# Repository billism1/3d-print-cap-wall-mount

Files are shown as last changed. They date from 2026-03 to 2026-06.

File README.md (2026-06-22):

# Cap Wall Mount – Hat Display System

> *Yes, it's a wall hook for hats. No, I didn't need to overthink it this much. But here we are — with optimized layer orientation, parametric everything, and a button cutout so your cap's top button doesn't get squished over the next decade.*

**[Available on MakerWorld](https://makerworld.com/en/models/2529196-baseball-cap-display-mount)**

A 3D-printable, parametric wall mount for displaying baseball caps. Fold a cap in half and slide its brim into the channel formed by two concentric arc walls — the cap hangs from a keyhole screw slot on the backplate, with an optional second screw hole below for extra security. The tapered backplate is designed to print on its side so FDM layer lines run along the arc walls for maximum strength. Mount several in a grid on your wall for easy display and selection.

For a cleaner look, mount the caps on a plexiglass panel and attach the panel to the wall using the included standoff tubes — this creates a floating display of baseball caps.

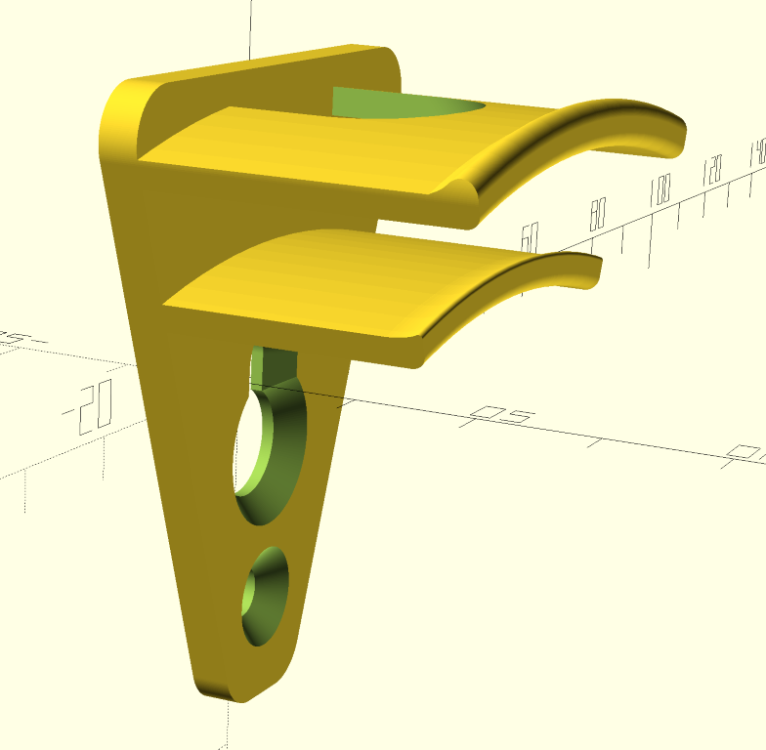
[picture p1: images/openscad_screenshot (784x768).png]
Cap Wall Mount preview


## Photos

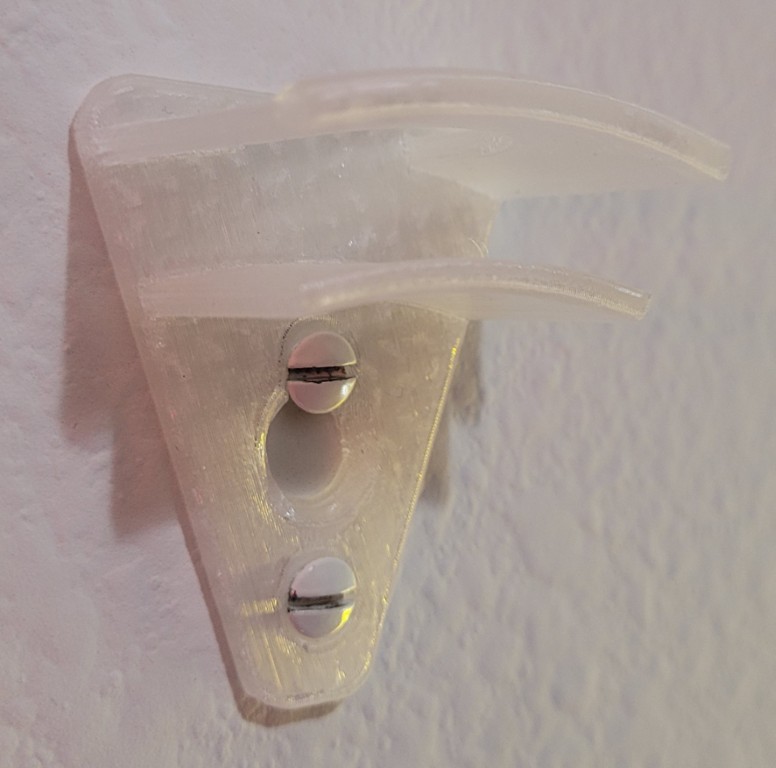
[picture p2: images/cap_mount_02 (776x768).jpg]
Single stand-alone wall mount secured to the wall


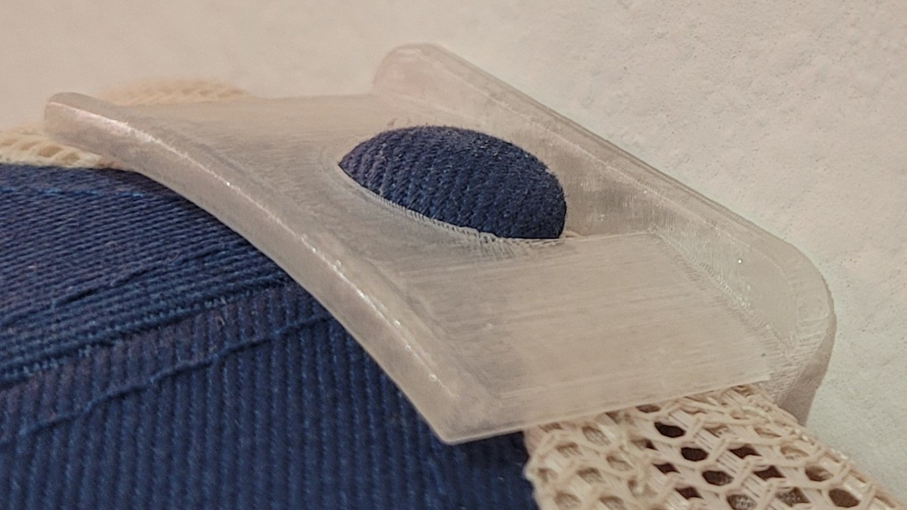
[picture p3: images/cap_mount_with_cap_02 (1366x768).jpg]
Close-up of top of mount and cap button being held in place to a single stand-alone wall mount secured to the wall


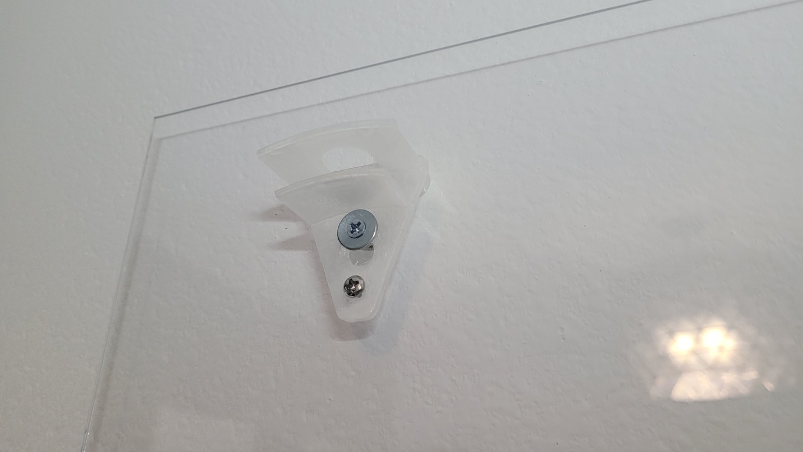
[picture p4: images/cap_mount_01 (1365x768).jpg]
Single cap mount secured to plexiglass with #6 bolts, nuts, and washers


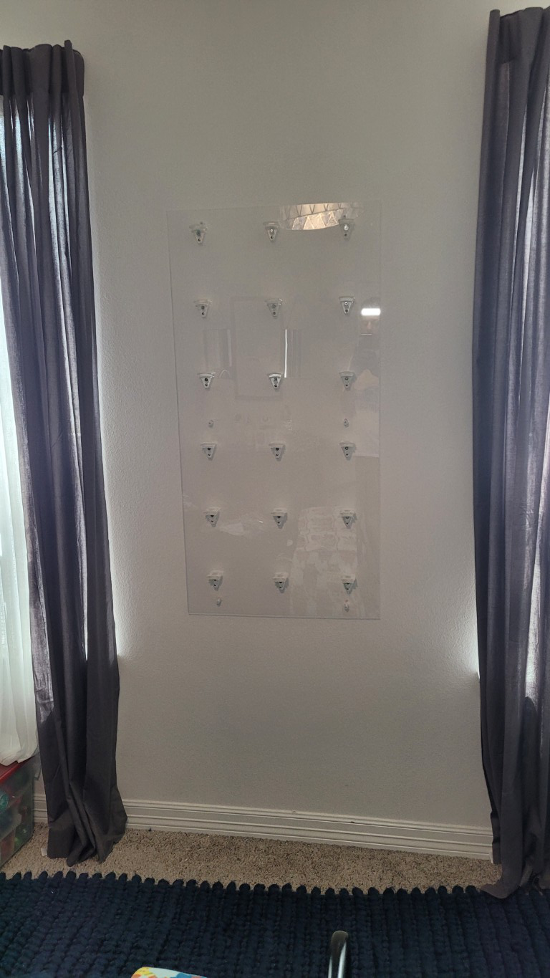
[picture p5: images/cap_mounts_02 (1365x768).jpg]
18 cap wall mounts arranged in 6 rows of 3 on a 24″ × 48″ plexiglass sheet


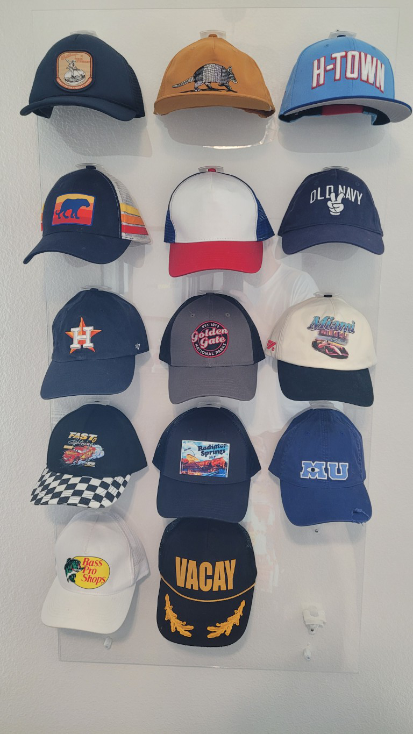
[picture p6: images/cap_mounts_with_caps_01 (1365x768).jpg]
Plexiglass panel mounted on the wall with most cap mounts holding caps


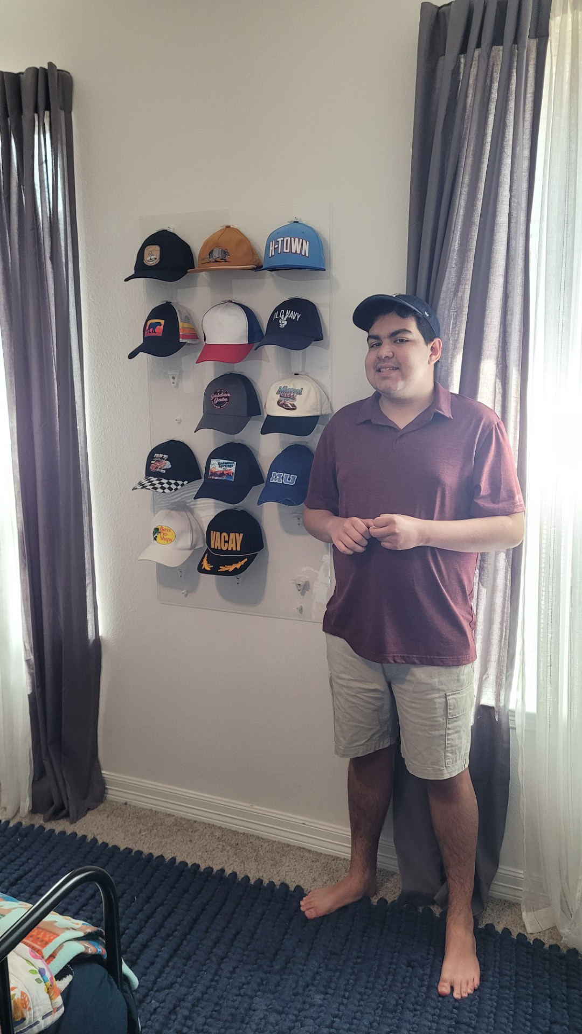
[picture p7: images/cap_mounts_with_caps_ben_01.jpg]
My son in front of his cap display - the baseball cap collector this was designed and printed for. If you know him, then you know that is a genuine smile.


*My son - the baseball cap collector this was designed and printed for. He's the one with the hat habit, not me. If you know him, then you know that is a genuine smile. Mission accomplished.*

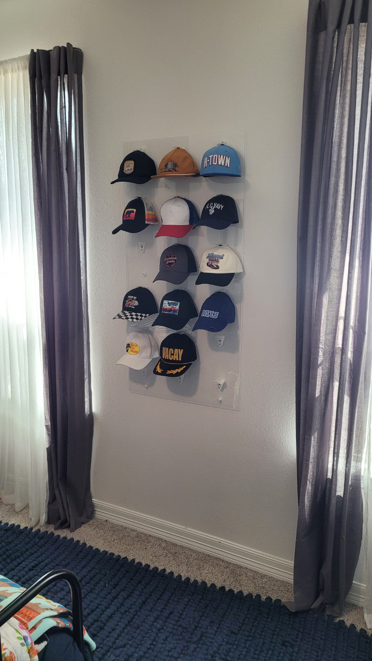
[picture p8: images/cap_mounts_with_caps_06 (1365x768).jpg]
Full plexiglass sheet with 18 cap mounts, most holding caps


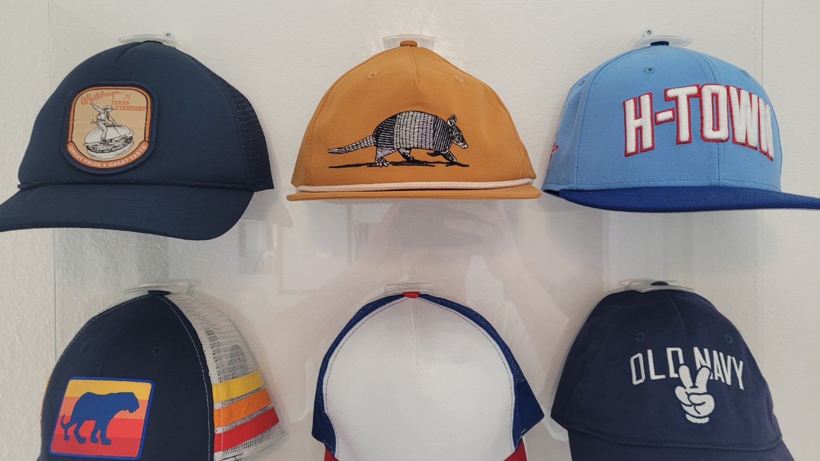
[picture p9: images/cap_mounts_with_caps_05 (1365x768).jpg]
Close-up of baseball caps displayed in the mounts


The plexiglass sheet is mounted to the wall using six standoff spacers (included in this repo) and six 3″ wood screws. The cap mounts are secured to the plexiglass with #6 bolts, nuts, and washers.

More photos are available in the [images](images/) folder.

## How It Works

The mount has four main parts:

1. **Backplate** — a flat plate with rounded corners that sits flush against the wall. It includes a keyhole screw slot (and optional bottom screw hole) so you can hang it on a drywall screw.
2. **Arc channel** — two concentric curved walls that extend forward from the backplate. They form a channel sized to hold a folded baseball cap by its brim/edge. The walls have filleted lower edges for smoother cap insertion and removal.
3. **Strap ridge** — the ridge on the top arc lets you hang a cap by its back strap if you don't care about the cap facing outward. If you prefer this style, you can set `inner_arc_enabled` to `false` since the inner arc wall isn't needed. On the outer arc wall near the front edge, a small curved bump prevents the cap's adjustable strap from sliding forward and off the mount.
4. **Button cutout** — an arched slot at the apex of the outer wall that gives the cap's top button room to sit without being compressed over time. The cutout tapers wider toward the inside face, letting the button settle naturally into the gap and making it easier to lift the cap off the mount.

## Features

- **Fully parametric** — every dimension is adjustable at the top of the `.scad` file.
- **Designed for strength** — intended to be printed on its side (tapered edge down) so that FDM layer lines run along the length of the arc walls rather than across them. This means the load from the hanging cap is carried in shear along the layers, not in tension across layer bonds — which is the weakest point of any FDM print. The result is arc walls that are far more resistant to snapping under load.
- **Tapered backplate** — the plate narrows toward the bottom at a configurable angle (`plate_taper_angle`, default 20°). This reduces material use and gives you a flat edge to place on the print bed when printing on its side. The angle is a clean multiple of 10° so rotation in the slicer is straightforward.
- **Grid-ready** — mount multiples in rows/columns on a wall.
- **Keyhole mounting** — hang on a single drywall screw; optional second screw hole for extra security.
- **Countersinks** — tapered recesses so screw heads sit flush against the wall.
- **Strap ridge** — keeps the cap's back strap from sliding off.
- **Inner arc ridge** — a small bump on the inner wall that helps hold the cap brim in the channel.
- **Button cutout** — prevents long-term compression of the cap's top button.
- **Filleted arc walls** — rounded lower edges on the arc walls for smoother cap insertion and removal.

## Customization

Open `src/cap-wall-mount.scad` in [OpenSCAD](https://openscad.org/) and edit the parameters at the top of the file:

### Backplate

| Parameter | Default | Description |
|---|---|---|
| `plate_width` | 45 mm | Width of the backplate (X axis) |
| `plate_height` | 50 mm | Height of the backplate (Y axis) |
| `plate_thickness` | 3 mm | Thickness of the backplate (Z axis) |
| `plate_corner_radius` | 4 mm | Fillet radius on the plate corners |
| `plate_taper_angle` | 20° | Taper angle from vertical (use a multiple of 10 for easy slicer rotation) |

### Screw Holes

| Parameter | Default | Description |
|---|---|---|
| `screw_holes_enabled` | true | Toggle all screw holes on/off |
| `keyhole_total_height` | 13 mm | Total height of the keyhole slot |
| `keyhole_bottom_diameter` | 8.5 mm | Diameter of the wide circle (screw head) |
| `keyhole_top_width` | 4 mm | Width of the narrow slot (screw shaft) |
| `keyhole_top_inset` | 21 mm | Distance from plate top edge to keyhole top |
| `bottom_screw_hole_enabled` | true | Toggle the bottom screw hole |
| `bottom_screw_hole_diameter` | 4 mm | Diameter of the bottom screw hole |
| `bottom_screw_hole_offset` | 6 mm | Gap between keyhole bottom and screw hole |
| `countersink_enabled` | true | Toggle countersink tapers on screw holes |
| `countersink_depth` | 2 mm | Depth of the countersink taper |
| `countersink_extra_dia` | 4 mm | Extra diameter of countersink beyond hole |

### Arc Channel

| Parameter | Default | Description |
|---|---|---|
| `inner_arc_enabled` | true | Toggle the inner arc wall on/off |
| `arc_radius` | 80 mm | Outer radius of the outer arc wall |
| `arc_sweep` | 38° | Half-sweep angle from apex (total arc = 2×) |
| `arc_wall_thickness` | 2.25 mm | Thickness of each arc wall |
| `arc_channel_gap` | 9 mm | Gap between inner and outer walls (cap fits here) |
| `outer_arc_extrusion` | 25 mm | How far the outer arc extends forward from the plate |
| `inner_arc_extrusion` | 20 mm | How far the inner arc extends forward from the plate |
| `arc_top_inset` | 2 mm | Distance from plate top edge to arc apex |
| `arc_wall_fillet` | 1.1 mm | Fillet radius on arc wall cross-section corners |

### Strap Ridge

| Parameter | Default | Description |
|---|---|---|
| `strap_ridge_enabled` | true | Toggle the strap ridge on/off |
| `strap_ridge_height` | 7 mm | How far the ridge protrudes outward |
| `strap_ridge_width` | 4 mm | Width of the ridge along the Z axis |

### Inner Arc Ridge

| Parameter | Default | Description |
|---|---|---|
| `inner_ridge_enabled` | true | Toggle the inner arc ridge on/off |
| `inner_ridge_height` | 1 mm | How far the ridge protrudes into the channel |
| `inner_ridge_width` | 3 mm | Width of the inner ridge along the Z axis |

### Button Cutout

| Parameter | Default | Description |
|---|---|---|
| `button_cutout_enabled` | true | Toggle the button cutout on/off |
| `button_cutout_width` | 17 mm | Width of the cutout in X |
| `button_cutout_height` | 15 mm | Height of the cutout from the plate surface in Z |

## Standoff Tube (`src/standoff-tube.scad`)

A simple cylindrical spacer tube sized for standard drywall screws. It sits between the plexiglass panel and the wall, holding the panel away from the wall surface to provide clearance for the screws that secure the cap mounts to the plexiglass. Drive a drywall screw through the plexiglass, through the standoff, and into the wall — the cap wall mounts are then attached to the front of the plexiglass, creating a floating display panel.

| Parameter | Default | Description |
|---|---|---|
| `inner_diameter` | 5.4 mm | Bore diameter (sized for your screw shaft) |
| `wall_thickness` | 4 mm | Radial wall thickness |
| `length` | 16 mm | Total tube length (standoff distance from wall) |
| `flat_edge` | false | Adds a flat along the length of the tube for printing on its side |

When `flat_edge` is enabled, the tube can be printed on its side so that FDM layer lines run axially along the tube length. This orients the layers parallel to the compressive load path between the wall and the plexiglass, maximising interlaminar shear strength and eliminating the risk of delamination under clamping force — the weakest failure mode when layers are perpendicular to the load.

## Usage

1. Open `src/cap-wall-mount.scad` in [OpenSCAD](https://openscad.org/).
2. Adjust parameters at the top of the file to fit your caps and screws.
3. Preview (**F5**) to check the shape, then render (**F6**).
4. Export to STL (**F7**).
5. Slice and print — rotate the model in your slicer so the tapered edge sits flat on the print bed (rotate by `plate_taper_angle`, default 20°). This orients the layer lines along the arc walls for maximum strength.
6. Drive a drywall screw into the wall, hang the mount via the keyhole, and slide a folded cap into the channel.

## Repository Layout

- `src/` — Editable OpenSCAD source/design files.
- `publication/` — Exported STL files ready for publishing.
- `images/` — Screenshots and renders.

## License

This project is licensed under the [MIT License](LICENSE).

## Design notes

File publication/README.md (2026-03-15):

# Publication Files

This folder contains exported files and platform-specific assets ready for publishing.

## Contents

- `STL/` — Exported STL files for 3D printing.
- `MakerWorld/` — Assets for the MakerWorld platform listing.

## Purpose
- Organize release-ready assets by publishing destination.
- Keep platform-specific metadata, screenshots, and packaged files grouped together.

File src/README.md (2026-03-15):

# Source Files

This folder contains the editable OpenSCAD source/design files for the cap wall mount system.

## Contents

- `cap-wall-mount.scad` — Parametric wall mount for displaying baseball caps.
- `standoff-tube.scad` — Cylindrical spacer tube for plexiglass panel standoffs.

## Purpose
- Keep the original, editable project files separate from published/exported files.
- Preserve your working design history and tool-specific assets.

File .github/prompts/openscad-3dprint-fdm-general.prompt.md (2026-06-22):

# OpenSCAD – General FDM 3D Printing Prompt

> Use this prompt for any OpenSCAD work targeting FDM (Fused Deposition Modelling) printers.

## Language Rules

OpenSCAD is a **functional CSG modelling language**, not a general-purpose programming language. Follow these rules exactly:

- **Do NOT use mutable variables** — compute all values at parse time
- **Do NOT use `for()` as control flow** — use it as a geometric generator only
- **Do NOT write functions that return values** — modules produce geometry, not data
- **Use `hull()` for fillets and smooth transitions**, not manual chamfer math
- **Use `let()` for named intermediate values** inside expressions
- **Use `each` to flatten nested lists** in list comprehensions
- **Use `children()`** when a module must operate on geometry passed to it
- **`difference()`, `union()`, `intersection()`** are the core boolean CSG operations — prefer these over complex nested geometry
- **`translate()`, `rotate()`, `scale()`** are transforms — always applied to children, never standalone
- **`$fn` controls curve smoothness** — always set it explicitly; never rely on the default

## FDM Design Principles

### Orientation matters
- The **flat, largest face should sit on the build plate** whenever possible.
- Minimise the need for support material by avoiding large unsupported overhangs.
- Vertical cylindrical holes print well; horizontal ones may need tear-drop or bridging profiles.

### Strength considerations
- **Layer lines are weakest in tension along Z.** Design load-bearing features so forces act across (XY) rather than between layers.
- Add fillets at the base of vertical features to distribute stress and reduce stress-risers.
- Prefer rounded transitions over sharp internal corners to avoid stress concentration.

### Printability guidelines
- Avoid very thin walls (< 2 × nozzle diameter). Typical minimum wall thickness: **0.8–1.2 mm** for a 0.4 mm nozzle.
- Bridging spans should stay under **~50 mm** without support.
- Overhangs up to **~45°** from vertical generally print without support; steeper angles may need chamfers or supports.
- Design snap-fits and living hinges with grain direction (layer orientation) in mind.

## OpenSCAD Cheatsheet

https://openscad.org/cheatsheet/

## Common Patterns

### Rounded rectangle (cube with round XY edges)
```openscad
module rounded_rect(size, r) {
    hull() {
        for (x = [r, size.x - r], y = [r, size.y - r])
            translate([x, y, 0])
                cylinder(r = r, h = size.z);
    }
}
```

### Fillet at base of a vertical feature
```openscad
module base_fillet(r, h) {
    difference() {
        cube([r, r, h]);
        translate([r, r, -0.01])
            cylinder(r = r, h = h + 0.02);
    }
}
```

### Chamfered hole (countersink / printer-friendly top)
```openscad
module chamfered_hole(d, h, chamfer = 0.6) {
    union() {
        cylinder(d = d, h = h);
        translate([0, 0, h - chamfer])
            cylinder(d1 = d, d2 = d + 2 * chamfer, h = chamfer + 0.01);
    }
}
```

### Shell / hollow box
```openscad
module shell(outer, wall) {
    difference() {
        cube(outer);
        translate([wall, wall, wall])
            cube([outer.x - 2*wall, outer.y - 2*wall, outer.z]);
    }
}
```

### Slot (elongated hole)
```openscad
module slot(length, d, h) {
    hull() {
        cylinder(d = d, h = h);
        translate([length, 0, 0])
            cylinder(d = d, h = h);
    }
}
```

### Counterbore hole
```openscad
module counterbore_hole(d_through, d_head, h_total, h_head) {
    union() {
        cylinder(d = d_through, h = h_total + 0.01);
        translate([0, 0, h_total - h_head])
            cylinder(d = d_head, h = h_head + 0.01);
    }
}
```

### Text / label emboss or deboss
```openscad
// Debossed (engraved) text on top surface
module debossed_label(txt, size, depth, font = "Liberation Sans:style=Bold") {
    translate([0, 0, -depth])
        linear_extrude(depth + 0.01)
            text(txt, size = size, font = font, halign = "center", valign = "center");
}
```

### Circular pattern (polar array)
```openscad
module polar_array(n, r) {
    for (i = [0 : n - 1])
        rotate([0, 0, i * 360 / n])
            translate([r, 0, 0])
                children();
}
```

## Tolerances for FDM 3D Printing

| Fit Type | Tolerance | Example |
|---|---|---|
| Press-fit (tight interference) | +0.1–0.2 mm on ID | `insert_od + 0.15` |
| Snug / sliding fit | +0.2–0.4 mm | `shaft_d + 0.3` |
| Loose / clearance fit | +0.5–1.0 mm | `cable_d + 0.6` |
| Screw through-hole | +0.3–0.5 mm | `M4 → 4.4 mm hole` |
| Self-threading (screw into plastic) | ~85% of nominal | `M4 → 3.4 mm hole` |
| Mating flat surfaces (stacking) | +0.2 mm per axis | offset to prevent binding |
| Lid / cap fit | +0.3–0.5 mm radial clearance | on diameter |

## Recommended `$fn` Values

| Feature | `$fn` | Notes |
|---|---|---|
| Small holes (< 6 mm) | 24–32 | Keeps file size small, holes still round |
| Medium cylinders (6–30 mm) | 48–64 | Good visual smoothness |
| Large curves / decorative | 96–128 | For visible surfaces |
| Hex shapes | 6 | `cylinder(..., $fn=6)` gives a hexagon |
| Quick preview / development | 16–24 | Faster render while iterating |
| Final export | 64–128 | Use higher values for production STL |

## CSG Best Practices

- Always extend cut volumes by **0.01 mm** (epsilon) beyond the surface to avoid z-fighting / coincident faces.
- Keep geometry **manifold** — no zero-thickness walls, no self-intersecting volumes.
- Use `render()` sparingly; it forces CGAL evaluation and slows preview.
- Name modules descriptively (e.g., `mounting_tab()`, `drain_slot()`) and parametrise dimensions at the top of the file.
- Group related constants together and comment units: `wall = 2.5; // mm`.
- Use `assert()` to guard against invalid parameter combinations.

## File Organisation

```
// 1. Constants & parameters
// 2. Derived dimensions
// 3. Helper / utility modules
// 4. Component modules
// 5. Assembly (top-level geometry)
```

Keep the top-level geometry at the **bottom** of the file so that reading top-to-bottom flows from parameters → helpers → final shape.

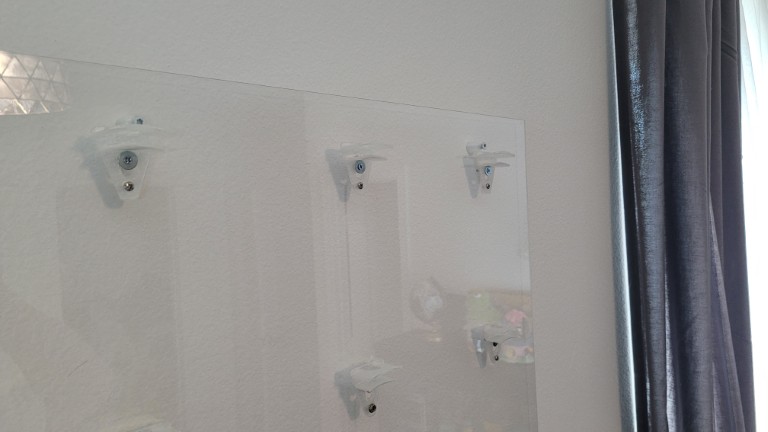
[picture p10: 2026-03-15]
images/cap_mounts_01 (768x432).jpg

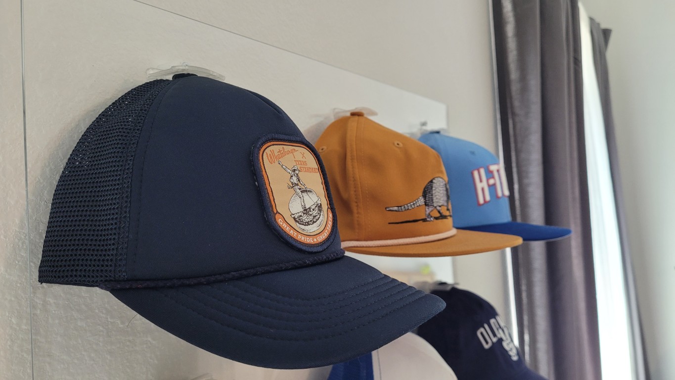
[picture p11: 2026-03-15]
images/cap_mounts_with_caps_04 (1365x768).jpg

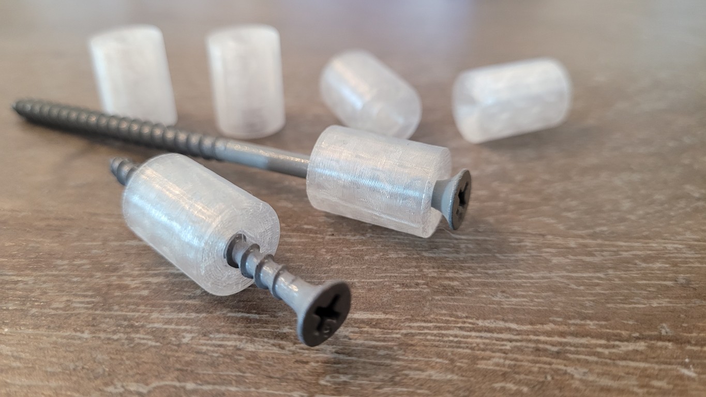
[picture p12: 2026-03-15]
images/stand_offs (1365x768).jpg

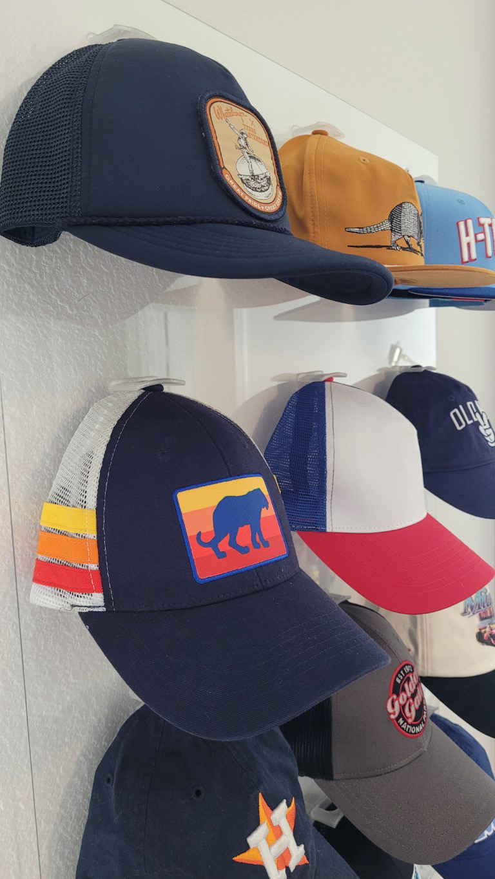
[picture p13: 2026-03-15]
images/cap_mounts_with_caps_03 (1365x768).jpg

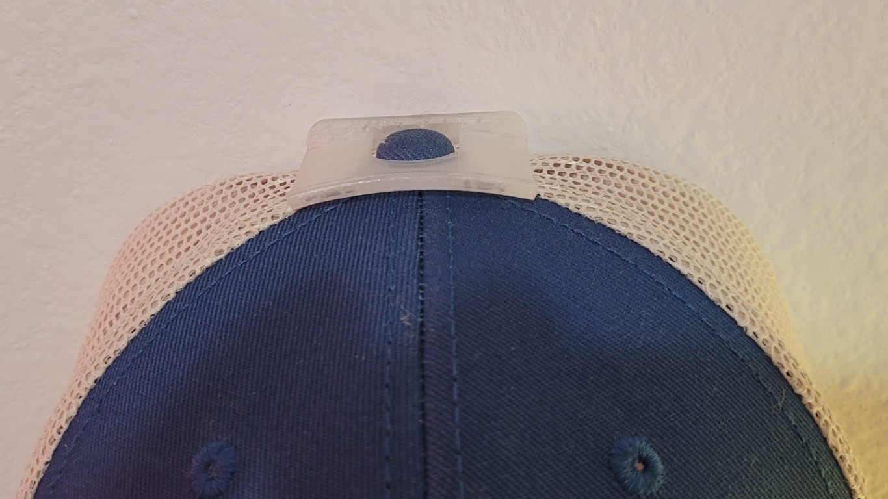
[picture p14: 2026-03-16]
images/cap_mount_with_cap_01 (1366x768).jpg

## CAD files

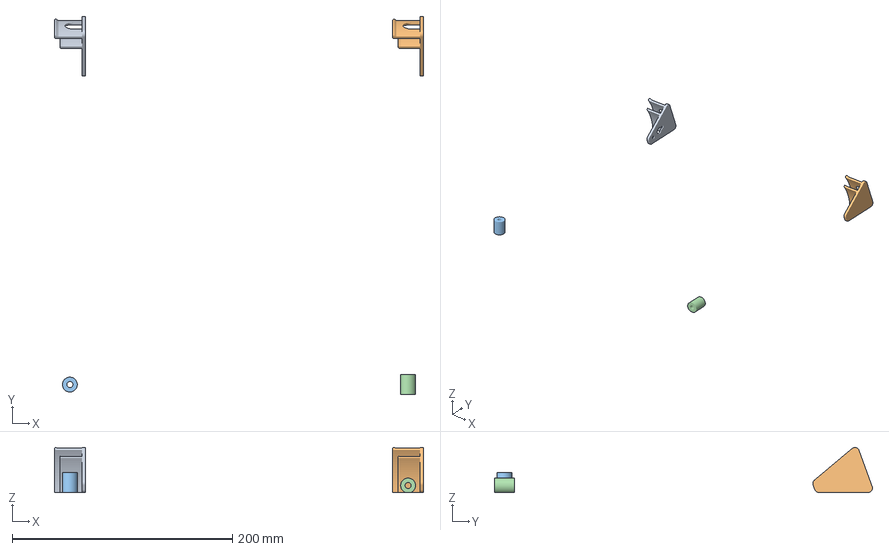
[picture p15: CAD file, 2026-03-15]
publication/MakerWorld/baseball cap wall mount.3mf
335.2 x 343.3 x 40.9 mm
cap-wall-mount-with-screw-holes.stl
cap-wall-mount-no-screw-holes.stl
standoff-tube.stl
standoff-tube-with-flat-edge.stl

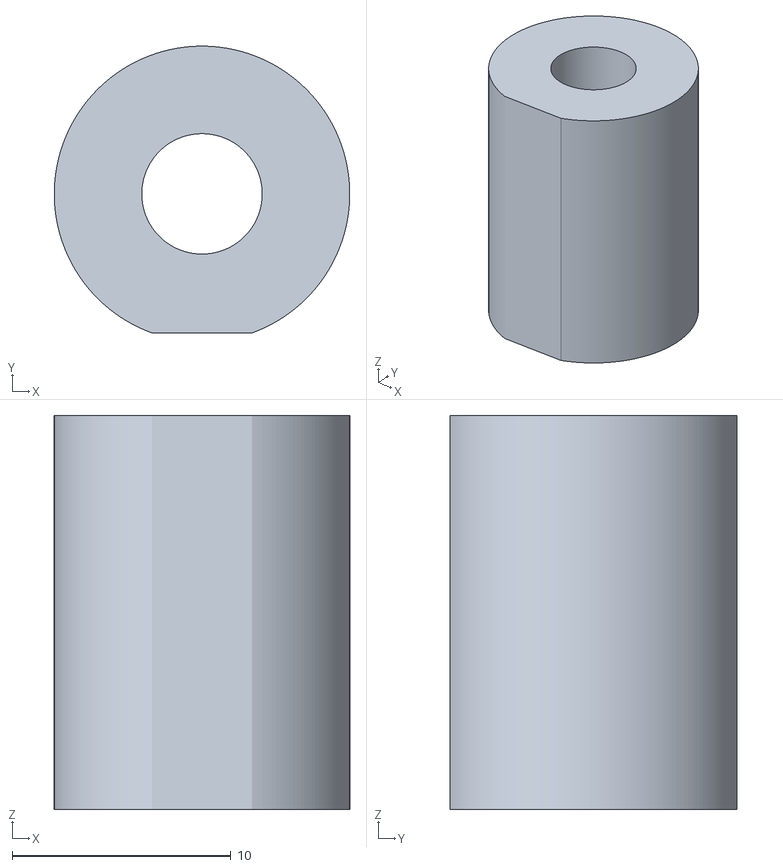
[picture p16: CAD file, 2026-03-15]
publication/STL/standoff-tube-with-flat-edge.stl
13.5 x 13.1 x 18.0

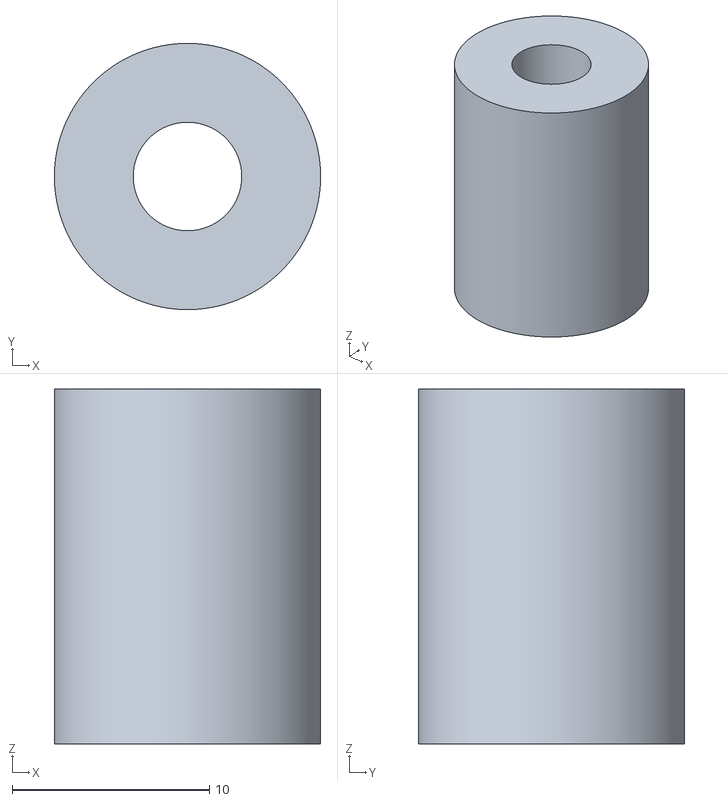
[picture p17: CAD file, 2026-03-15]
publication/STL/standoff-tube.stl
13.5 x 13.5 x 18.0

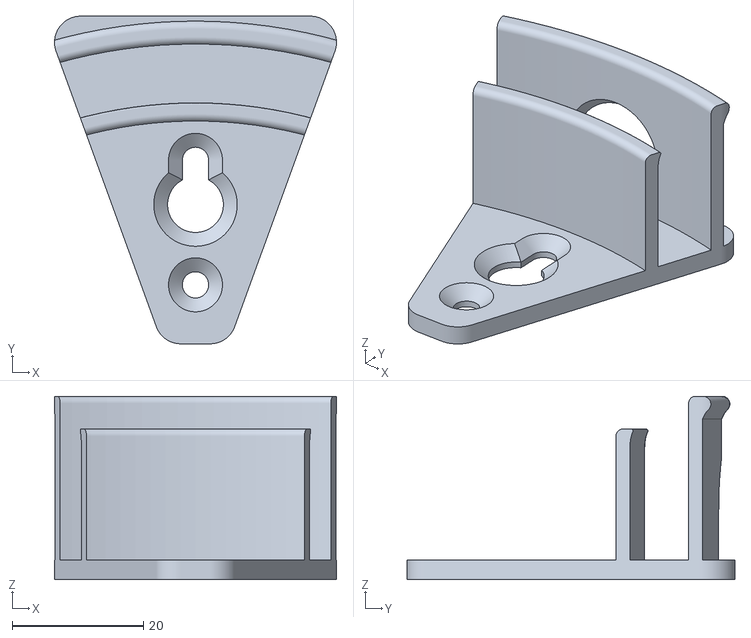
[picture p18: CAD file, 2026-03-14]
publication/STL/cap-wall-mount-with-screw-holes.stl
43.0 x 50.0 x 28.0

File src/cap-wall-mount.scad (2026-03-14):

// =============================================================================
// Cap Wall Mount – Hat Display System
// =============================================================================
// A parametric wall-mounted cap/hat holder for displaying baseball caps in a
// grid matrix on a wall for display and selection.
//
// The mount consists of a flat backplate (with a keyhole screw slot) and one
// pair of concentric arc walls forming a channel. The arcs are partial rings
// in the XY plane, with their apex pointing +Y (upward when mounted).
// The arcs are extruded forward in +Z from the plate surface. A folded
// baseball cap's edge rides in the channel between the two walls.
//
// Model orientation: backplate in XY plane (Z=0..plate_thickness).
// Arcs are partial rings in XY, apex at +Y, extruded in +Z.
// =============================================================================

// ---------------------------------------------------------------------------
// 1. Constants & Parameters
// ---------------------------------------------------------------------------

// Backplate
plate_width              = 45;    // mm – plate width  (X axis)
plate_height             = 50;    // mm – plate height (Y axis)
plate_thickness          = 3;     // mm – plate thickness (Z axis)
plate_corner_radius      = 4;     // mm – fillet radius on plate corners
plate_taper_angle        = 20;    // deg – taper angle from vertical (use multiple of 10 for easy print rotation)

// Keyhole screw slot 
screw_holes_enabled      = true;  // Whether to include the keyhole and screw holes
keyhole_total_height     = 13;    // mm – total height of keyhole slot
keyhole_bottom_diameter  = 8.5;     // mm – wide hole for screw head
keyhole_top_width        = 4;     // mm – narrow slot for screw shaft
keyhole_top_inset        = 20;     // mm – distance from plate top edge to keyhole top

// Bottom screw hole (below keyhole)
bottom_screw_hole_enabled = true;  // Whether to include the bottom screw hole
bottom_screw_hole_diameter = 4;    // mm – diameter of bottom screw hole
bottom_screw_hole_offset = 6;     // mm – gap between keyhole bottom edge and screw hole edge

// Countersink (tapered recess for drywall screw heads)
countersink_enabled      = true;  // Whether to add tapered countersinks
countersink_depth        = 2;     // mm – depth of the tapered countersink
countersink_extra_dia    = 4.25;     // mm – how much wider the countersink is than the hole

// Arc channel (cap cradle) — concentric partial rings in XY, extruded in Z
inner_arc_enabled        = true;  // Whether to include the inner arc wall
arc_radius               = 80;    // mm – outer radius of outer wall 
arc_sweep                = 38;    // deg – half-sweep from apex (total swing = 2×this)
arc_wall_thickness       = 2.25;     // mm – thickness of each arc wall
arc_channel_gap          = 9.5;    // mm – gap between walls (folded cap fits here)
outer_arc_extrusion      = 25;    // mm – how far outer arc extends forward from plate face
inner_arc_extrusion      = 20;    // mm – how far inner arc extends forward from plate face
arc_top_inset            = 2;     // mm – distance from plate top edge to arc apex
arc_wall_fillet          = 1.1;     // mm – fillet radius on arc wall cross-section corners

// Strap ridge (prevents cap back strap from sliding forward off the arc)
strap_ridge_enabled      = true;  // Whether to add a ridge on the outer arc
strap_ridge_height       = 7;     // mm – how far the ridge protrudes outward
strap_ridge_width        = 4;     // mm – width of the ridge along the Z axis

// Inner arc ridge (matching ridge on the inner/lower arc wall)
inner_ridge_enabled      = true;  // Whether to add a ridge on the inner arc
inner_ridge_height       = 1;     // mm – how far the ridge protrudes outward (into the channel)
inner_ridge_width        = 3;     // mm – width of the inner ridge along the Z axis

// Button cutout (gap at apex of outer arc for cap button)
button_cutout_enabled    = true;  // Whether to cut a button slot in the outer arc
button_cutout_width      = 17;    // mm – width of the cutout in X
button_cutout_height     = 15;    // mm – height of the cutout from plate surface in Z

// Build flags
build_main               = true;  // Render the mount

// Resolution
$fn = 180;

// ---------------------------------------------------------------------------
// 2. Derived Dimensions
// ---------------------------------------------------------------------------

// Wall radii (measured from arc centre)
_outer_wall_inner_r      = arc_radius - arc_wall_thickness;
_inner_wall_outer_r      = _outer_wall_inner_r - arc_channel_gap;
_inner_wall_inner_r      = _inner_wall_outer_r - arc_wall_thickness;

// Z extent: arcs go through plate and extend forward
_outer_arc_total_z       = plate_thickness + outer_arc_extrusion;
_inner_arc_total_z       = plate_thickness + inner_arc_extrusion;

// Arc centre: positioned so apex is at plate top edge minus inset (+Y)
_arc_center_y            = plate_height / 2 - arc_top_inset - arc_radius;

// Arc endpoint positions (where the arc ends meet the plate)
_arc_endpoint_x          = arc_radius * sin(arc_sweep);

// Tapered plate: narrows from full width at arc apex to narrow bottom
_taper_start_y           = plate_height / 2 - arc_top_inset; // Y where taper begins
_taper_run               = _taper_start_y + plate_height / 2; // vertical distance of taper
_bottom_plate_width      = max(
    2 * bottom_screw_hole_diameter,  // minimum: must fit bottom screw hole
    plate_width - 2 * _taper_run * tan(plate_taper_angle)
);  // width at bottom edge, derived from taper angle

echo(str("Channel gap: ", arc_channel_gap, " mm"));
echo(str("Outer wall: R ", _outer_wall_inner_r, " to ", arc_radius));
echo(str("Inner wall: R ", _inner_wall_inner_r, " to ", _inner_wall_outer_r));
echo(str("Arc centre Y: ", _arc_center_y));
echo(str("Arc apex Y: ", _arc_center_y + arc_radius));
echo(str("Arc endpoint X: ±", _arc_endpoint_x, " mm"));

// Keyhole geometry
_keyhole_bottom_r        = keyhole_bottom_diameter / 2;
_keyhole_top_r           = keyhole_top_width / 2;
// Top of keyhole (top of narrow slot semicircle) at plate_height/2 - inset
_keyhole_top_cy          = plate_height / 2 - keyhole_top_inset - _keyhole_top_r;
_keyhole_bottom_cy       = _keyhole_top_cy - keyhole_total_height
                           + _keyhole_top_r + _keyhole_bottom_r;

// ---------------------------------------------------------------------------
// 3. Helper / Utility Modules
// ---------------------------------------------------------------------------

// Rounded rectangle centred on XY origin, extruded in +Z
module rounded_rect_centred(size, r) {
    translate([-size.x / 2, -size.y / 2, 0])
        hull() {
            for (x = [r, size.x - r], y = [r, size.y - r])
                translate([x, y, 0])
                    cylinder(r = r, h = size.z);
        }
}

// 2D profile of the tapered backplate (full width at top, narrow at bottom)
module _plate_profile_2d() {
    offset(r = plate_corner_radius) offset(delta = -plate_corner_radius)
        polygon([
            [-plate_width / 2,          plate_height / 2],
            [ plate_width / 2,          plate_height / 2],
            [ plate_width / 2,          _taper_start_y],
            [ _bottom_plate_width / 2, -plate_height / 2],
            [-_bottom_plate_width / 2, -plate_height / 2],
            [-plate_width / 2,          _taper_start_y]
        ]);
}

// Partial ring with a curved (quarter-circle) cross-section for smooth ridge.
// Sits at outer radius `radius`, curves outward by `height` and along Z by `width`.
// The tip is rounded by an offset-round technique.
module arc_ridge(radius, height, width, sweep) {
    _ridge_steps = 16;
    _tip_r = min(height, width) * 0.3;  // rounding radius for the sharp tip
    _ext = _tip_r * 2;                  // base extension to hide offset erosion
    rotate([0, 0, 90 - sweep])
        rotate_extrude(angle = 2 * sweep)
            translate([radius, 0])
                intersection() {
                    // Keep only the positive-X region (don't bleed into wall)
                    square([height + 1, width + 1]);
                    // Round outer corners; base edges extend deep into wall
                    // so offset erosion artifacts are fully clipped away
                    offset(r = _tip_r) offset(delta = -_tip_r)
                        polygon([
                            [-_ext, -_ext],
                            [-_ext, 0],
                            for (i = [0 : _ridge_steps])
                                let(a = 90 * i / _ridge_steps)
                                [height * (1 - cos(a)), width * sin(a)],
                            [-_ext, width],
                            [-_ext, width + _ext]
                        ]);
                }
}
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

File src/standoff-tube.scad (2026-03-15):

// =============================================================================
// Standoff Tube
// =============================================================================
// A simple cylindrical standoff / spacer tube for FDM printing.
// =============================================================================

// ---------------------------------------------------------------------------
// 1. Constants & Parameters
// ---------------------------------------------------------------------------

inner_diameter = 5.5;   // mm – bore diameter
wall_thickness = 4;     // mm – radial wall thickness
length         = 18;    // mm – total tube length (Z axis)
flat_edge      = false; // add a flat along the length for printing on its side

// Resolution
$fn = 180;

// ---------------------------------------------------------------------------
// 2. Derived Dimensions
// ---------------------------------------------------------------------------

outer_diameter = inner_diameter + 2 * wall_thickness;
_flat_cut      = outer_diameter / 2 - wall_thickness * 0.1; // cut depth leaves a flat

// ---------------------------------------------------------------------------
// 3. Assembly
// ---------------------------------------------------------------------------

difference() {
    intersection() {
        cylinder(d = outer_diameter, h = length);
        if (flat_edge)
            translate([-outer_diameter / 2, -_flat_cut, 0])
                cube([outer_diameter, _flat_cut + outer_diameter / 2, length]);
    }
    translate([0, 0, -0.01])
        cylinder(d = inner_diameter, h = length + 0.02);
}

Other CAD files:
publication/STL/cap-wall-mount-no-screw-holes.stl

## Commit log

2026-03-13 Initial commit: parametric cap wall mount for hat display grid
    [cap-wall-mount.scad]
2026-03-13 Replace design with boilerplate OpenSCAD template
    [cap-wall-mount.scad]
2026-03-13 initial 3d design.
    [cap-wall-mount.scad]
2026-03-13 Single arch channel spanning -X to +X using rotate_extrude
    [cap-wall-mount.scad]
2026-03-14 cut off excess width of the arcs.
    [cap-wall-mount.scad]
2026-03-14 param for including screw holes
    [cap-wall-mount.scad]
2026-03-14 countersunk screw holes.
    [cap-wall-mount.scad]
2026-03-14 add arc top inset parameter and adjust arc center positioning
    [cap-wall-mount.scad]
2026-03-14 top arc ridge.
    [cap-wall-mount.scad]
2026-03-14 refine arc ridge module with improved tip rounding and offset handling
    [cap-wall-mount.scad]
2026-03-14 adjust arc wall thickness and increase strap ridge height for improved cap support
    [cap-wall-mount.scad]
2026-03-14 update README.md for clarity and detail; modify STL file for improved design
    [cap-wall-mount-with-screw-holes.stl]
2026-03-14 v2 (narrow bottom)
    [cap-wall-mount.scad]
2026-03-14 add taper angle parameter for improved design flexibility in cap wall mount
    [cap-wall-mount-with-screw-holes_v2.stl, cap-wall-mount.scad]
2026-03-14 update keyhole dimensions for improved fit and functionality in cap wall mount
    [cap-wall-mount-with-screw-holes_v2.stl, cap-wall-mount.scad]
2026-03-14 update README.md for clarity and detail; enhance descriptions of design features and printing instructions
2026-03-14 refine backplate dimensions and enhance arc channel design for improved cap fit
    [cap-wall-mount.scad]
2026-03-14 update STL files for cap wall mount; remove outdated version and modify screenshot
    [cap-wall-mount-with-screw-holes.stl, cap-wall-mount-with-screw-holes_v2.stl]
2026-03-14 update arc channel gap in cap wall mount design for improved cap fit
    [cap-wall-mount-with-screw-holes.stl, cap-wall-mount.scad]
2026-03-14 update keyhole dimensions in cap wall mount design for improved screw fit
    [cap-wall-mount-with-screw-holes.stl, cap-wall-mount.scad]
2026-03-14 update keyhole top inset in cap wall mount design for improved alignment
    [cap-wall-mount-with-screw-holes.stl, cap-wall-mount.scad]
2026-03-14 add btton gap with taper.
    [cap-wall-mount.scad]
2026-03-14 update button cutout height in cap wall mount design for improved fit
    [cap-wall-mount.scad]
2026-03-14 update cap wall mount STL file to include screw holes for improved installation
    [cap-wall-mount-with-screw-holes.stl]
2026-03-14 refactor cap wall mount design to separate outer and inner arc extrusion parameters for improved customization
    [cap-wall-mount-with-screw-holes.stl, cap-wall-mount.scad]
2026-03-14 update inner arc ridge dimensions for improved fit and functionality
    [cap-wall-mount.scad]
2026-03-14 add arc wall fillet parameter for improved aesthetic and structural integrity
    [cap-wall-mount.scad]
2026-03-14 update inner ridge width in cap wall mount design for improved fit
    [cap-wall-mount.scad]
2026-03-14 update cap wall mount STL file to include screw holes for enhanced mounting options
    [cap-wall-mount-with-screw-holes.stl]
2026-03-14 update arc wall fillet radius for improved structural integrity
    [cap-wall-mount.scad]
2026-03-14 update arc channel gap in cap wall mount design for improved fit
    [cap-wall-mount-with-screw-holes.stl, cap-wall-mount.scad]
2026-03-14 Change back plate from 4 mm thicknes to 3 mm thickness to save material - it is strong enough.
    [cap-wall-mount-with-screw-holes.stl, cap-wall-mount.scad]
2026-03-14 Fine-tuning some dimensions/params. Update STL renderings.
    [cap-wall-mount-no-screw-holes.stl, cap-wall-mount-with-screw-holes.stl, cap-wall-mount.scad]
2026-03-14 Enhance README and SCAD file: clarify strap ridge functionality and add inner arc toggle parameter
    [cap-wall-mount.scad]
2026-03-15 Add standoff tube design and update README for floating display option
    [standoff-tube.scad, standoff-tube.stl]
2026-03-15 Add flat edge option to standoff tube for improved printing orientation
    [standoff-tube-with-flat-edge.stl, standoff-tube.scad]
2026-03-15 Update standoff tube dimensions and add flat edge parameter for improved printing
    [standoff-tube-with-flat-edge.stl, standoff-tube.scad, standoff-tube.stl]
2026-03-15 Increase stand-off tube innter diam.
    [standoff-tube-with-flat-edge.stl, standoff-tube.scad, standoff-tube.stl]
2026-03-15 Rearranging files.
    [cap-wall-mount-no-screw-holes.stl, cap-wall-mount-with-screw-holes.stl, cap-wall-mount.scad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]
2026-03-15 Adding Maker World (3mf) file.
    [baseball cap wall mount.3mf]
2026-03-15 Update README and add new images for cap wall mount display
2026-03-15 Repalced custom filament with generic filament typ ein 3mf file.
    [baseball cap wall mount.3mf]
2026-03-16 Add new images for cap wall mount display in README
